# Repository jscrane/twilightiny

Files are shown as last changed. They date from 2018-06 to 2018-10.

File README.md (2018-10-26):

View this project on [CADLAB.io](https://cadlab.io/project/1197). 

Twilight-3
==========

Twilight with attiny85,
[Interrupted](https://github.com/jscrane/Interrupted) and
[Tiny Safe Boot](http://jtxp.org/tech/tinysafeboot_en.htm).

Hardware
--------
The layout in version [#1](https://cadlab.io/project/1197/6bfdd5cf1f4ba5d0182bede7adce6e52f376f4fe/circuit/ZWFnbGUvdHdpbGlnaHQzLmJyZA%3D%3D) is broken, 
there's a short in the power circuit. (Never ignore ERC warnings!)

Version [#2](https://cadlab.io/project/1197/2f3ed3901fa7b14418fc2b612dbf1835c0194fca/circuit/ZWFnbGUvdHdpbGlnaHQzLmJyZA%3D%3D) has been built and tested. 
Depending on the PIR sensor used, the 22k resistor is optional. If present,
it drags down the output of 
[Mini-PIRs](https://www.futurlec.com/Mini_PIR_Module.shtml) too much.

Version [#3](https://cadlab.io/project/1197/9cf4fb193adf9d36c94b128c8913e801d072b348/circuit/ZWFnbGUvdHdpbGlnaHQzLmJyZA%3D%3D) improves the layout some more
but is (so far) untested.

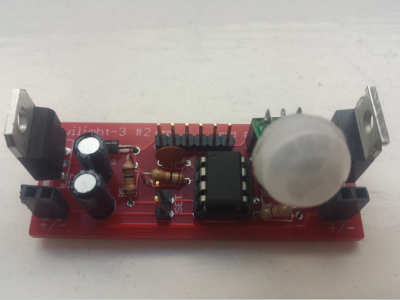
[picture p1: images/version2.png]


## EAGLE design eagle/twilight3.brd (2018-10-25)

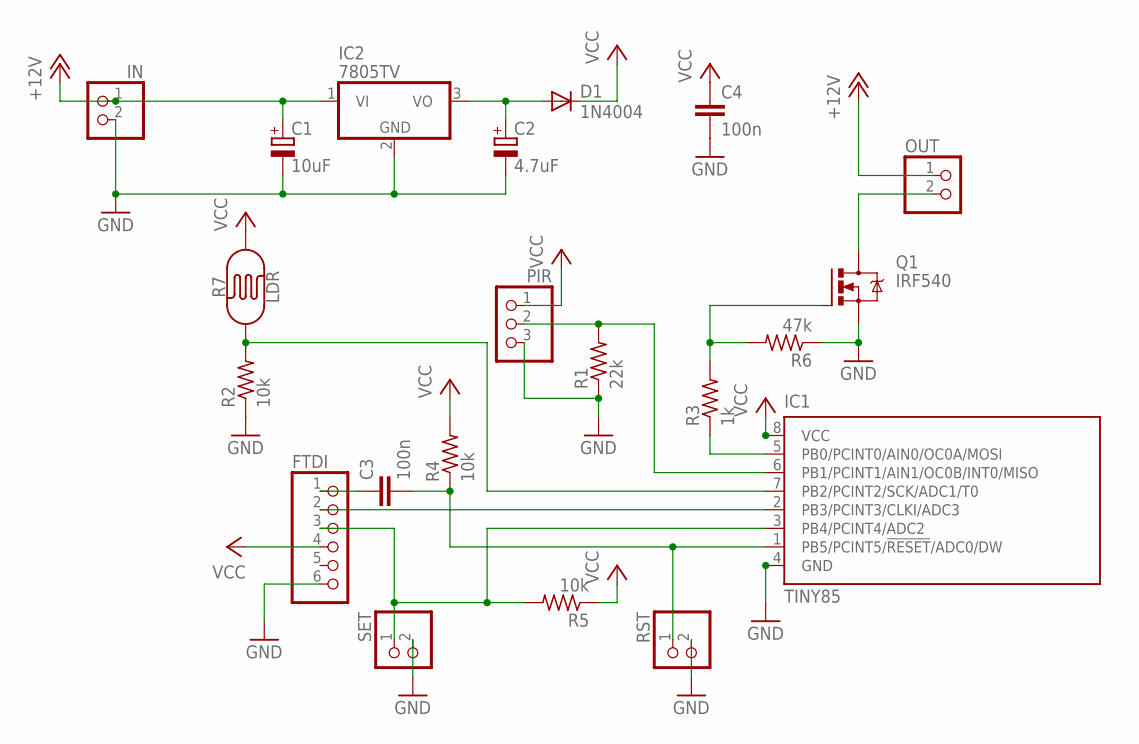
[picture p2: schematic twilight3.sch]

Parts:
C1: 10uF; E2-5
C2: 4.7uF; E2-5
C3, C4: 100n; C050-024X044
D1: 1N4004; DO41-10
FTDI: PINHD-1X6; 1X06
IC1: TINY85; DIL08
IC2: 7805TV; TO220V
IN: PINHD-1X2; 1X02
OUT: PINHD-1X2; 1X02
PIR: PINHD-1X3; 1X03
Q1: IRF540; TO220BV
R1: 22k; 0207/2V
R2, R4, R5: 10k; 0207/2V
R3: 1k; 0207/10
R6: 47k; 0207/10
R7: LDR; PHOTOCELL
RST: PINHD-1X2; 1X02
SET: PINHD-1X2; 1X02

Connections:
+12V: C1.+, IC2.1 (VI), IN.1, OUT.1
GND: C1.-, C2.-, C4.2, FTDI.6, IC1.4 (GND), IC2.2 (GND), IN.2, PIR.3, Q1.S, R1.1, R2.1, R6.1, RST.2, SET.2
GNDOUT: OUT.2, Q1.D
unnamed: FTDI.2, IC1.2 (PB3/PCINT3/CLKI/ADC3)
unnamed: FTDI.3, IC1.3 (PB4/PCINT4/ADC2), R5.2, SET.1
unnamed: C3.2, IC1.1 (PB5/PCINT5/!RESET!/ADC0/DW), R4.1, RST.1
unnamed: IC1.7 (PB2/PCINT2/SCK/ADC1/T0), R2.2, R7.1
unnamed: IC1.5 (PB0/PCINT0/AIN0/OC0A/MOSI), R3.1
unnamed: Q1.G, R3.2, R6.2
unnamed: C3.1, FTDI.1
unnamed: C2.+, D1.A, IC2.3 (VO)
unnamed: IC1.6 (PB1/PCINT1/AIN1/OC0B/INT0/MISO), PIR.2, R1.2
VCC: C4.1, D1.C, FTDI.4, IC1.8 (VCC), PIR.1, R4.2, R5.1, R7.2

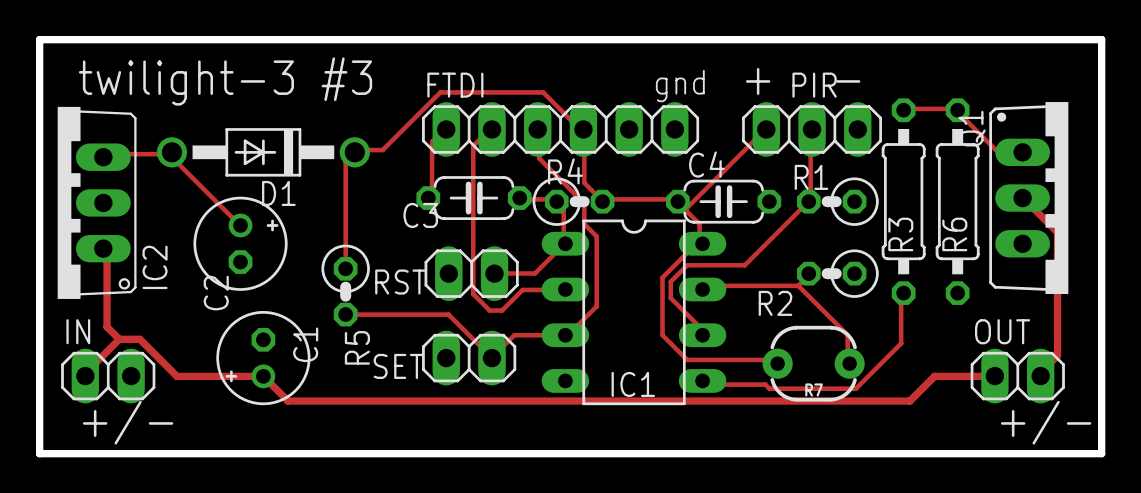
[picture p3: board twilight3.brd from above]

Board: 2 copper layers, 59.0 x 23.0 mm, 21 parts (0 on the bottom side), 13 nets.

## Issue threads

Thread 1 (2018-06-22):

Hardware: add reset header to board

jscrane, 2018-06-22:
Debugging output from the board interferes with TSB's ability to install new firmware.

Therefore a way of resetting the CPU without power-cycling would be nice.

Closed 2018-10-25.

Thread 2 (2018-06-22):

Hardware: PIR socket is not pin-compatible with "Mini PIRs"

jscrane, 2018-06-22:
It would be nice to be able to plug these guys straight into the board, without requiring jumper cables.

This means swapping the GND and Signal pins.

jscrane, 2018-06-28:
fixed in 2f3ed39

Closed 2018-06-28.

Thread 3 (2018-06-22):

Hardware: add polarity labels to JP1 and JP2

jscrane, 2018-06-22:
Unclear which way round the power connects.

jscrane, 2018-06-28:
fixed in 2f3ed39

Closed 2018-06-28.

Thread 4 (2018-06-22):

Hardware: short-circuit to ground in power supply

jscrane, 2018-06-22:
The header JP1 is shorted out by the power rail. This will have to be laid out again.

In the meantime: DON'T use this layout!

jscrane, 2018-06-28:
fixed in 2f3ed39

Closed 2018-06-28.

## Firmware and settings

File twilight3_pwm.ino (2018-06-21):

#include <EEPROM.h>
#ifdef DEBUG
#include <TinyDebugSerial.h>
#endif
#include <Interrupted.h>

#define SAMPLES		30	// number of samples to smooth for dark level
#define THRESHOLD	80	// default dark level
#define ON_TIME		120	// how long to stay on for with no movement
#define HOLD_TIME	2000	// how long to hold button to store dark level

#define LDR	A1
#define LED	0
#define PIR	1
#define TIMER	2
#define FADER	3
#define BUTTON	4

#define FADE_ON		0
#define FADE_OFF	255

#ifdef DEBUG
TinyDebugSerial serial;
#endif
Analog ldr(LDR);
Port portb;
Pin button(BUTTON, portb, HIGH);
Pin pir(PIR, portb);
Watchdog timer(TIMER, 1);
Delay fader(FADER, 20);
Devices devices;

unsigned threshold = THRESHOLD, smoothed = threshold, ontime = 0;
byte v = FADE_OFF;
bool on = false;
long downtime;

unsigned sample(int curr) {
	static int samples[SAMPLES], pos = 0;
	static long total = 0, ns = 0;

	if (ns < SAMPLES) ns++;
	total += curr - samples[pos];
	samples[pos++] = curr;
	if (pos == SAMPLES) pos = 0;
	return (unsigned)(total / ns);
}

void setup() {
	pinMode(PIR, INPUT);
	pinMode(BUTTON, INPUT_PULLUP);
	pinMode(LED, OUTPUT);

	devices.add(pir);
	devices.add(button);
	devices.add(ldr);
	devices.add(timer);
	devices.add(fader);
	devices.begin();

	uint8_t t = EEPROM[0];
	unsigned d = 1000;
	if (t != 0xff) {
		d = 200;
		threshold = 4*t;
	}
	
	// enable PWM on PB0 (OCR0A)
	TCCR0A = _BV(COM0A1) | _BV(COM0A0) | _BV(WGM01) | _BV(WGM00);
	TCCR0B = _BV(CS01);

	// flash at startup
	OCR0A = FADE_ON;
	delay(d);
	OCR0A = FADE_OFF;

	timer.enable();

#ifdef DEBUG
	serial.begin(115200);
#endif
}

static bool fading() {
	return (on && v != FADE_ON) || (!on && v != FADE_OFF);
}

void loop() {
#ifdef DEBUG
	serial.print("threshold=");
	serial.print(threshold);
	serial.print(" smoothed=");
	serial.print(smoothed);
	serial.print(" pir=");
	serial.print(pir.is_on());
	serial.print(" button=");
	serial.print(button.is_on());
	serial.print(" on=");
	serial.print(on);
	serial.print(" v=");
	serial.print(v);
	serial.print(" ontime=");
	serial.println(ontime);
#endif
	switch (devices.select()) {
	case LDR:
		smoothed = sample(ldr.read());
		timer.enable();
		break;
	case TIMER:
		ldr.enable();	// sample ldr every second
		if (ontime > 0)
			ontime--;
		else if (on) {
			fader.enable();	// fade out
			on = false;
		}
		break;
	case PIR:
#ifdef DEBUG
		serial.print("pir=");
		serial.println(pir.is_high());
#endif
		if (pir.is_high() && smoothed < threshold) {
			if (!on) {	// fade in
				fader.enable();
				on = true;
			}
			ontime = ON_TIME;
		}
		break;		
	case FADER:
		OCR0A = on? --v: ++v;
		fader.enable(fading());
		break;
	case BUTTON:
#ifdef DEBUG
		serial.print("button=");
		serial.println(button.is_high());
#endif
		// flip LED state
		on = !on;
		OCR0A = on? FADE_ON: FADE_OFF;
		if (button.is_low()) {
			pir.disable();
			timer.disable();
			ldr.disable();
			fader.disable();
			downtime = millis();
		} else {
			pir.enable();
			timer.enable();
			fader.enable(fading());
			threshold = smoothed + 1;
			if (millis() - downtime > HOLD_TIME)
				EEPROM[0] = threshold / 4;
		}
		break;
	}
}

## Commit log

2018-06-21 add eagle
    [twilight3.brd, twilight3.sch]
2018-06-28 fix issues #2, #3 and #4
    [twilight3.brd, twilight3.sch]
2018-10-21 improve labelling
    [twilight3.brd]
2018-10-23 changing resistor sizes and orientations; move ldr to edge of board
    [twilight3.brd, twilight3.sch]
2018-10-25 adding bypass capacitor
    [twilight3.brd, twilight3.sch]
2018-10-25 add reset header
    [twilight3.brd, twilight3.sch]

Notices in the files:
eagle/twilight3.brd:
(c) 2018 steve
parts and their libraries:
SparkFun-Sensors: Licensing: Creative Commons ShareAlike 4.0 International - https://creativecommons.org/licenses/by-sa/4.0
